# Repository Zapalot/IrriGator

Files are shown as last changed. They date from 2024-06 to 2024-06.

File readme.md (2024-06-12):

This is the irrigation scheduler currently under development.

It consists of..
- one (and possibly later multiple) PCB designs in KiCad
- An Arduino Program for ESP32

It depends on

- ArduPar3
- ArduParWeb

When finished, it will provide the following functionality:

- Actuating solenoid valves, fans, lights and other actuators based on schedules and/or sensor measurements
- Web interface for configuring schedules and other settings
- logging and display of sensor data
- external RTC support for hassle free time keeping

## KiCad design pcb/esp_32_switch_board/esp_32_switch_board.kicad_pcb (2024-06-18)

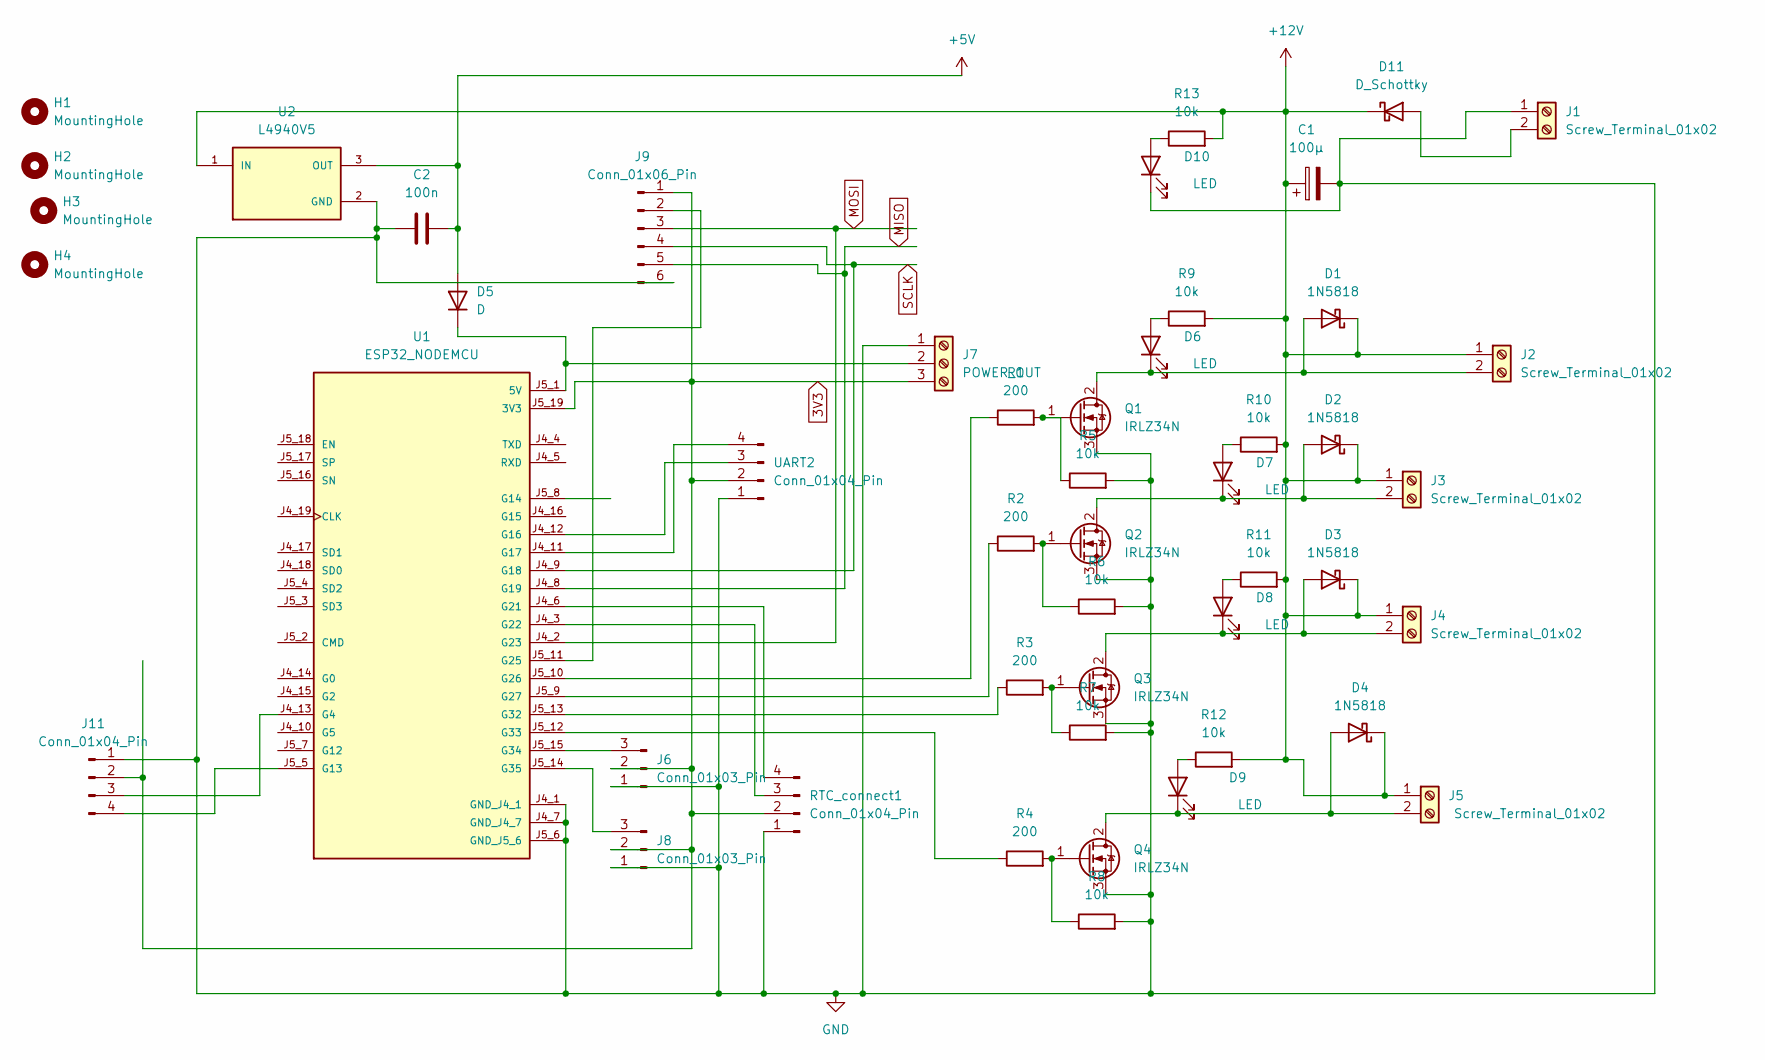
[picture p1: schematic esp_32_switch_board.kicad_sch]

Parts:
C1: 100µ; CP_Radial_D8.0mm_P2.50mm
C2: 100n; C_Disc_D5.0mm_W2.5mm_P5.00mm
D1, D2, D3, D4: 1N5818; D_DO-41_SOD81_P10.16mm_Horizontal
D5: D; D_DO-15_P10.16mm_Horizontal
D6, D7, D8, D9, D10: LED; LED_D3.0mm
D11: D_Schottky; D_DO-201AD_P15.24mm_Horizontal
H1, H2, H3, H4: MountingHole; MountingHole_3.2mm_M3_ISO14580_Pad
J1, J2, J3, J4, J5: Screw_Terminal_01x02; TerminalBlock_MetzConnect_Type101_RT01602HBWC_1x02_P5.08mm_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
J6, J8: Conn_01x03_Pin; JST_XH_B3B-XH-A_1x03_P2.50mm_Vertical
J7: POWER_OUT; TerminalBlock_MetzConnect_Type101_RT01603HBWC_1x03_P5.08mm_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
J9: Conn_01x06_Pin; PinHeader_1x06_P2.54mm_Vertical
J11: Conn_01x04_Pin; JST_XA_B04B-XASK-1_1x04_P2.50mm_Vertical
Q1, Q2, Q3, Q4: IRLZ34N; TO-220-3_Vertical
R1, R2, R3, R4: 200; R_Axial_DIN0207_L6.3mm_D2.5mm_P10.16mm_Horizontal
R5, R6, R7, R8, R9, R10, R11, R12, R13: 10k; R_Axial_DIN0207_L6.3mm_D2.5mm_P10.16mm_Horizontal
RTC_connect1: Conn_01x04_Pin; PinHeader_1x04_P2.54mm_Vertical
U1: ESP32_NODEMCU; MODULE_ESP32_NODEMCU
U2: L4940V5; TO225P1040X460X1968-3; PARTREV 14
UART2: Conn_01x04_Pin; JST_XA_B04B-XASK-1_1x04_P2.50mm_Vertical

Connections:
3V3: J6.2, J7.3, J8.2, J9.1, J11.2, RTC_connect1.2, U1.J5_19 (3V3), UART2.2
+5V: C2.2, D5.2 (A), U2.3 (OUT)
+12V: C1.1, D1.1 (K), D2.1 (K), D3.1 (K), D4.1 (K), D11.1 (K), J2.1, J3.1, J4.1, J5.1, R9.2, R10.2, R11.2, R12.2, R13.2, U2.1 (IN)
GND: C1.2, C2.1, D10.1 (K), J1.1, J6.1, J7.1, J8.1, J9.6, J11.1, Q1.3 (S), Q2.3 (S), Q3.3 (S), Q4.3 (S), R5.2, R6.2, R7.2, R8.2, RTC_connect1.1, U1.J4_1 (GND_J4_1), U1.J4_7 (GND_J4_7), U1.J5_6 (GND_J5_6), U2.2 (GND), UART2.1
MISO: J9.5, U1.J4_8 (G19)
MOSI: J9.3, U1.J4_2 (G23)
unnamed: D1.2 (A), D6.1 (K), J2.2, Q1.2 (D)
unnamed: D2.2 (A), D7.1 (K), J3.2, Q2.2 (D)
unnamed: D3.2 (A), D8.1 (K), J4.2, Q3.2 (D)
unnamed: D4.2 (A), D9.1 (K), J5.2, Q4.2 (D)
unnamed: D5.1 (K), J7.2, U1.J5_1 (5V)
unnamed: D6.2 (A), R9.1
unnamed: D7.2 (A), R10.1
unnamed: D8.2 (A), R11.1
unnamed: D9.2 (A), R12.1
unnamed: D10.2 (A), R13.1
unnamed: D11.2 (A), J1.2
unnamed: J6.3, U1.J5_15 (G34)
unnamed: J8.3, U1.J5_14 (G35)
unnamed: J9.2, U1.J5_11 (G25)
unnamed: J11.3, U1.J4_13 (G4)
unnamed: J11.4, U1.J5_5 (G13)
unnamed: Q1.1 (G), R1.2, R5.1
unnamed: Q2.1 (G), R2.2, R6.1
unnamed: Q3.1 (G), R3.2, R7.1
unnamed: Q4.1 (G), R4.2, R8.1
unnamed: RTC_connect1.3, U1.J4_3 (G22)
unnamed: RTC_connect1.4, U1.J4_6 (G21)
unnamed: U1.J4_12 (G16), UART2.3
unnamed: U1.J4_11 (G17), UART2.4
unnamed: R1.1, U1.J5_10 (G26)
unnamed: R2.1, U1.J5_9 (G27)
unnamed: R3.1, U1.J5_13 (G32)
unnamed: R4.1, U1.J5_12 (G33)
SCLK: J9.4, U1.J4_9 (G18)

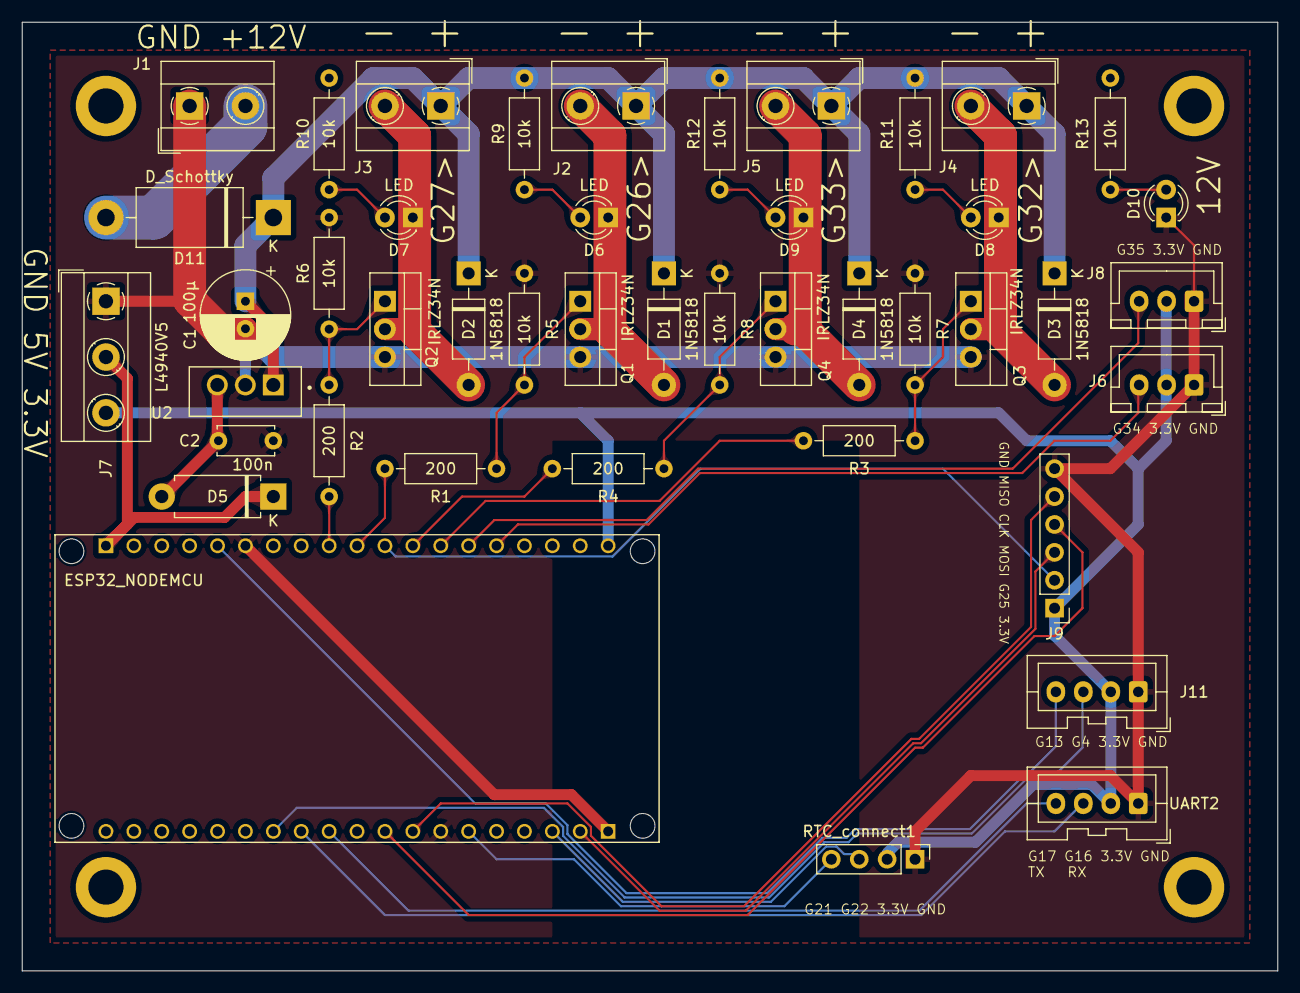
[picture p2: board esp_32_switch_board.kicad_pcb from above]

Board: 2 copper layers, 114.3 x 86.4 mm, 48 parts (0 on the bottom side), 35 nets.

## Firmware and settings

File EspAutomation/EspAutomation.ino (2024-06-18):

#include "ArduPar3.h"
#include "ArduParWeb.h"

ArduPar3Collection parameterCollection; // create a collection for parameters so we can conveniently do things with all of them at once
CallbackArduPar3 dumpCallbackParameter;
CallbackArduPar3 loadCallbackParameter;
CallbackArduPar3 saveCallbackParameter;

//////////////////////////Everything WiFi
#include <esp_wifi.h>
#include <WiFi.h>
#include "credentials.h"
void setupWifi(const char *ssid, const char *password);

///////////////////everything Web///
#include <WiFiClient.h>
#include <WebServer.h>

WebServer server(80);
void notFound();           // function to call on unknon URIs
void serveArduParFormUi(); // function to serve our UI

#include "WebFormArduParUiEntry.h"
#include "WebFormSection.h"
#include "WebFormHtmlPage.h"
#include "WebFormDebugElement.h"
#include "WebFormArduParUiBuilder.h"

WebFormArduParUiBuilder arduParUi;
WebFormDebugElement debugSection(&server);

//////////////Here comes the actual automation

////Time related things
#define NTP_SERVER "pool.ntp.org"
#define UTC_OFFSET 0
#define UTC_OFFSET_DST 0

#include <time.h>
#include "TimeBase.h"
SystemTimeBase timeBase; // this is what we use while the code is running

#include <Wire.h>
#include <RTClib.h> // this one we use to set the time once on startup
#define rtcClockPin 21
#define rtcDataPin 22

// read external RTC to set internal clock
void setSytemClockFromRtc()
{
    TwoWire rtcWire(0);
    RTC_DS3231 rtc;
    rtcWire.begin(rtcDataPin, rtcClockPin, 10000);
    if (!rtc.begin(&rtcWire))
    {
        Serial.println(F("Couldn't find RTC!"));
        return;
    }
    if (rtc.lostPower())
    {
        Serial.println(F("RTC lost power,you need to set the time!"));
        rtc.adjust(DateTime(1718298024));
        return;
    }
    DateTime now = rtc.now();
    char datebuffer[] = "DDD, DD MMM YYYY hh:mm:ss";
    now.toString(datebuffer); // this crashes unfortunately
    Serial.print("Time read from RTC is: ");
    Serial.println(datebuffer);
    timeval curTime;
    curTime.tv_sec = now.unixtime(); // not year 2038 save!
    curTime.tv_usec = 0;
    settimeofday(&curTime, NULL);
}

#include "LedcPwmPin.h"
#define nValves 4
int valvePinNumbers[] = {26, 27, 32, 33};
LedcPwmPin valvePins[nValves];

#include "PulseSustainActuator.h"
const char *valveActuatorNames[] = {"/actuators/valve1", "/actuators/valve2", "/actuators/valve3", "/actuators/valve4"};
PulseSustainActuator valveActuators[nValves];

#include "ScheduledOnOffController.h"
const char *valveControllerNames[] = {"/schedules/valve1", "/schedules/valve2", "/schedules/valve3", "/schedules/valve4"};
ScheduledOnOffController valveControllers[nValves];

//////////Measurements and logging
int sdCsPin = 25;
#include <vector>
#include "src/measurements/Measurements.h"
#include "src/measurements/BufferedChannelCollection.h"
#include "src/measurements/sources/DummyMeasurementChannel.h"
#include "src/measurements/logging/LogTargets.h"
#include "src/measurements/logging/SdCardLogTarget.h"
#include "src/measurements/logging/BufferedMeasurementLogger.h"

#include "src/measurements/web/MeasurementChannelWebDisplayTable.h"
#include "src/measurements/web/ChannelCollectionWebView.h"
DummyMeasurementChannel counterChannel;
std::vector<AbstractMeasurementChannel *> measurementChannels; // here we keep all out measurements
BufferedChannelCollection measurementBuffer;                   // we use this to keep a number of past measurements in memory (i.e. for displaying them in a graph)
SdCardLogTarget logTargetSd;
SerialLogTarget logTargetSerial;
BufferedMeasurementLogger measurementLogger;
WebFormHtmlPage sensorPage("Sensor States");
MeasurementChannelWebDisplayTable sensorTable;
ChannelCollectionWebView sensorWebDisplay(&measurementBuffer);
void downloadLogFile(); // instruct the server to download the logfile

void setup()
{
    Serial.begin(115200);
    setSytemClockFromRtc();
    // configTime(UTC_OFFSET, UTC_OFFSET_DST, NTP_SERVER);
    // set up parameter infrastructure
    ArduPar3Collection::globalDefaultCollection = &parameterCollection; // use our parameter collection as a default
    dumpCallbackParameter.setup(PSTR("/commands/dump"), PSTR("Print Parameter Summary"), []
                                { parameterCollection.dumpParameterInfos(&Serial); });
    loadCallbackParameter.setup(PSTR("/commands/load"), PSTR("Load Settings."), []
                                { parameterCollection.loadAll(); });
    saveCallbackParameter.setup(PSTR("/commands/save"), PSTR("Save Settings."), []
                                { parameterCollection.saveAll(); });

    // set up automation
    for (int i = 0; i < nValves; i++)
    {
        valvePins[i].setup(valvePinNumbers[i], 20000, 8);
        valveActuators[i].setup(valveActuatorNames[i], "Valve actuator", &valvePins[i], 500, 255, 128, 0);
        valveControllers[i].setup(&valveActuators[i], valveControllerNames[i], "On/Off Schedule", &timeBase, ScheduledOnOffController::ScheduleTimeBaseHours, 0, 24, 1);
    }
    /// try to get connected to a WiFi
    setupWifi(WIFI_SSID, WIFI_PASSWORD);
    /// setup server
    server.on("/", serveArduParFormUi);
    server.onNotFound(notFound);
    server.begin();

    // build user interface
    arduParUi.buildUi(ArduPar3Collection::globalDefaultCollection, "/");

    parameterCollection.loadAll();
    //parameterCollection.dumpParameterInfos(&Serial);

    // set up measurements and logging
    measurementChannels.reserve(1);
    measurementChannels.push_back(&counterChannel);
    measurementBuffer.setup(&measurementChannels, 128);
    measurementBuffer.minPushIntervalMillis = 10;
    logTargetSd.setup("/test.txt", sdCsPin);
    measurementLogger.setup(&measurementBuffer, &logTargetSd);

    // set up page for displaying sensor values
    sensorTable.channels = measurementChannels;
    sensorPage.uiElements.push_back(&sensorWebDisplay);
    server.on("/sense", []()
              { sensorPage.serveYourself(server); });
             
    // allow logfile download
    server.on("/log", downloadLogFile);
}

void loop()
{
    // run measurements and logging
    counterChannel.update();
    measurementBuffer.pushMeasurementsToBufferInterval();
    measurementLogger.update();
    // update parameters from web and serial

    parameterCollection.updateParametersFromStream(&Serial, 1000);
    server.handleClient();
    /*
        // update controllers + actuators
        Serial.print("Hours of year:\t");
        Serial.print(timeBase.getHoursOfTheDay());
        Serial.print("\tValve States:\t");
        for (int i = 0; i < nValves; i++)
        {
            Serial.print(valvePins[i].getOutput());
            Serial.print("\t");
            valveControllers[i].update();
        }
        Serial.print("\n");
        */
    delay(2); // allow the cpu to switch to other tasks
}

void setupWifi(const char *ssid, const char *password)
{

    Serial.print("Connecting to wifi network \"");
    Serial.print(ssid);
    Serial.print("\" .");
    WiFi.mode(WIFI_STA);
    WiFi.begin(ssid, password);

    long start = millis();
    // try for ten seconds to connect every 500 ms (i.e. make 10000/500 = 20 attempts)
    while (WiFi.status() != WL_CONNECTED && millis() - start < 4000)
    {
        Serial.print(".");
        delay(500);
    }

    // print result of connection attempt(s) on serial console
    if (WiFi.status() != WL_CONNECTED)
    {
        Serial.print(" failed with status ");
        Serial.println(WiFi.status());
    }
    else
    {
        Serial.println(" succeeded");
        Serial.print("local IP address is ");
        Serial.println(WiFi.localIP());
        esp_wifi_set_ps(WIFI_PS_NONE);
    }
}
// function to serve our UI
void serveArduParFormUi()
{

    String message = "_________new Request!\n";
    message += "URI: ";
    message += server.uri();
    message += "\nMethod: ";
    message += (server.method() == HTTP_GET) ? "GET" : "POST";
    message += "\nArguments: ";
    message += server.args();
    message += "\n";
    for (uint8_t i = 0; i < server.args(); i++)
    {
        message += " " + server.argName(i) + ": " + server.arg(i) + "\n";
    }
    Serial.println(message);

    String pageContent;
    pageContent.reserve(8192);
    arduParUi.reactToRequest(server);
    arduParUi.generateHtml(pageContent);
    server.send(200, "text/html", pageContent);
}

void notFound()
{
    String message = "File Not Found\n\n";
    message += "URI: ";
    message += server.uri();
    message += "\nMethod: ";
    message += (server.method() == HTTP_GET) ? "GET" : "POST";
    message += "\nArguments: ";
    message += server.args();
    message += "\n";
    for (uint8_t i = 0; i < server.args(); i++)
    {
        message += " " + server.argName(i) + ": " + server.arg(i) + "\n";
    }
    server.send(404, "text/plain", message);
}
// instruct the server to download the logfile
void downloadLogFile()
{
    File download = SD.open(logTargetSd.getFilename(), "r");
    if (download)
    {
        server.sendHeader("Content-Type", "text/text");
        server.sendHeader("Content-Disposition", String("attachment; filename=") + logTargetSd.getFilename());
        server.sendHeader("Connection", "close");
        server.streamFile(download, "application/octet-stream");
        download.close();
    }
    else
    {
        String message = "Couldn't open file for download.\n";
        server.send(404, "text/plain", message);
    }
}

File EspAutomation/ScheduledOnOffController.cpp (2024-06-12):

#include "ScheduledOnOffController.h"
void ScheduledOnOffController::setup(AbstractSingleChannelActuator *actuator,
                                     String addressPrefix, String description,
                                     AbstractTimeBase* timeBase,
                                     ScheduleTimeBaseUnit timeBaseUnit,
                                     float defaultCycleStart,
                                     float defaultCycleLength,
                                     float defaultOnTime)
{

    // buint addresses for parameters
    cycleStartName=addressPrefix+"/cycleStart";
    cycleLengthName=addressPrefix+"/cycleLength";
    onTimeName=addressPrefix+"/onTime";
    scheduleEnabledName=addressPrefix+"/enableSchedule";

    burstDurationName=addressPrefix+"/burstDuration";
   startBurstName=addressPrefix+"/startBurst";
   stopBurstName=addressPrefix+"/stopBurst";
    float maxCycleLength;
    switch (    timeBaseUnit)
    {
    case ScheduleTimeBaseHours:
        maxCycleLength=24*7;
        break;
            case ScheduleTimeBaseMinutes:
        maxCycleLength=24*60;
        break;
            case ScheduleTimeBaseSeconds:
        maxCycleLength=60*60;
        break;
    default:
        break;
    }

    cycleStartPar.setup(cycleStartName.c_str(),"Cycle Start (New Year 0:00 = 0)",0,maxCycleLength);
    cycleLengthPar.setup(cycleLengthName.c_str(),"Cycle Length (hours)",0,maxCycleLength);
    onTimePar.setup(onTimeName.c_str(),"On Time (hours)",0,maxCycleLength);
    scheduleEnabledPar.setup(scheduleEnabledName.c_str(),"Enable Schedule");

    burstDurationPar.setup(burstDurationName.c_str(),"Burst Duration",0,24);
    startBurstPar.setup(startBurstName.c_str(),"Start Burst!",std::bind(&ScheduledOnOffController::startBurst, this));
    stopBurstPar.setup(stopBurstName.c_str(),"Stop Burst!",std::bind(&ScheduledOnOffController::stopBurst, this));

    this->timeBaseUnit=timeBaseUnit;
    this->timeBase=timeBase;
    this->myActuator=actuator;

    lastBurstStartTime=-1000000ll*3600ll*24ll*356ll; // make sure the burst is already over...
}

void ScheduledOnOffController::update( )
{
    int64_t curTime=timeBase->getLocalUnixTimeMicros();
    int64_t microsSinceBurstStart=(curTime-lastBurstStartTime);
    bool burstIsActive=microsSinceBurstStart<(int64_t)(burstDurationPar.getValue()*timeBaseUnitMultiplier);

   // onTimePar.setMax(cycleLengthPar.getValue());

    int64_t cycleStartMicros=(int64_t)(cycleStartPar.getValue()*timeBaseUnitMultiplier);
    int64_t cycleLengthMicros=(int64_t)(cycleLengthPar.getValue()*timeBaseUnitMultiplier);
    int64_t onTimeMicros=(int64_t)(onTimePar.getValue()*timeBaseUnitMultiplier);

    int64_t microsInInterval=(int64_t)(curTime-cycleStartMicros)%max((int64_t)cycleLengthMicros,(int64_t)1);
/*
    Serial.print("curTime=");
    Serial.println(curTime);

    Serial.print("timeBaseUnitMultiplier=");
    Serial.println(timeBaseUnitMultiplier);

    Serial.print("cycleLengthMicros=");
    Serial.println(cycleStartMicros);

    Serial.print("onTimeMicros=");
    Serial.println(onTimeMicros);
*/
    Serial.print("microsSinceBurstStart=");
    Serial.println(microsSinceBurstStart);

    Serial.print("burstDuration");
    Serial.println(burstDurationPar.getValue()*timeBaseUnitMultiplier);

    Serial.print("microsInInterval=");
    Serial.println(microsInInterval);

    bool isOn=(microsInInterval<onTimeMicros)&&scheduleEnabledPar.getValue()||burstIsActive;
    myActuator->setIntensityBool(isOn);
}
// start an unscheduled actuator activation
void ScheduledOnOffController::startBurst(){
    lastBurstStartTime=timeBase->getLocalUnixTimeMicros();
} 
// stop an unscheduled actuator activation
void ScheduledOnOffController::stopBurst(){
    lastBurstStartTime=-1000000ll*3600ll*24ll*356ll; // make sure the burst is already over...
}
